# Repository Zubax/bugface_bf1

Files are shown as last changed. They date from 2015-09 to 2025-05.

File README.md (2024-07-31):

# Zubax BugFace BF1

Zubax BugFace BF1 (formerly known as Dronecode Probe) is a generic JTAG/SWD+UART console adapter compatible with most ARM Cortex based designs and in particular with the hardware maintained by the [Dronecode project](http://dronecode.org/).

The design is based on Black Magic Probe and is distributed under open source licenses. The full description of its features and supported targets can be found at the [Black Magic Probe homepage](https://black-magic.org/).

For the manufacturing instructions refer to [MANUFACTURING.md](MANUFACTURING.md).

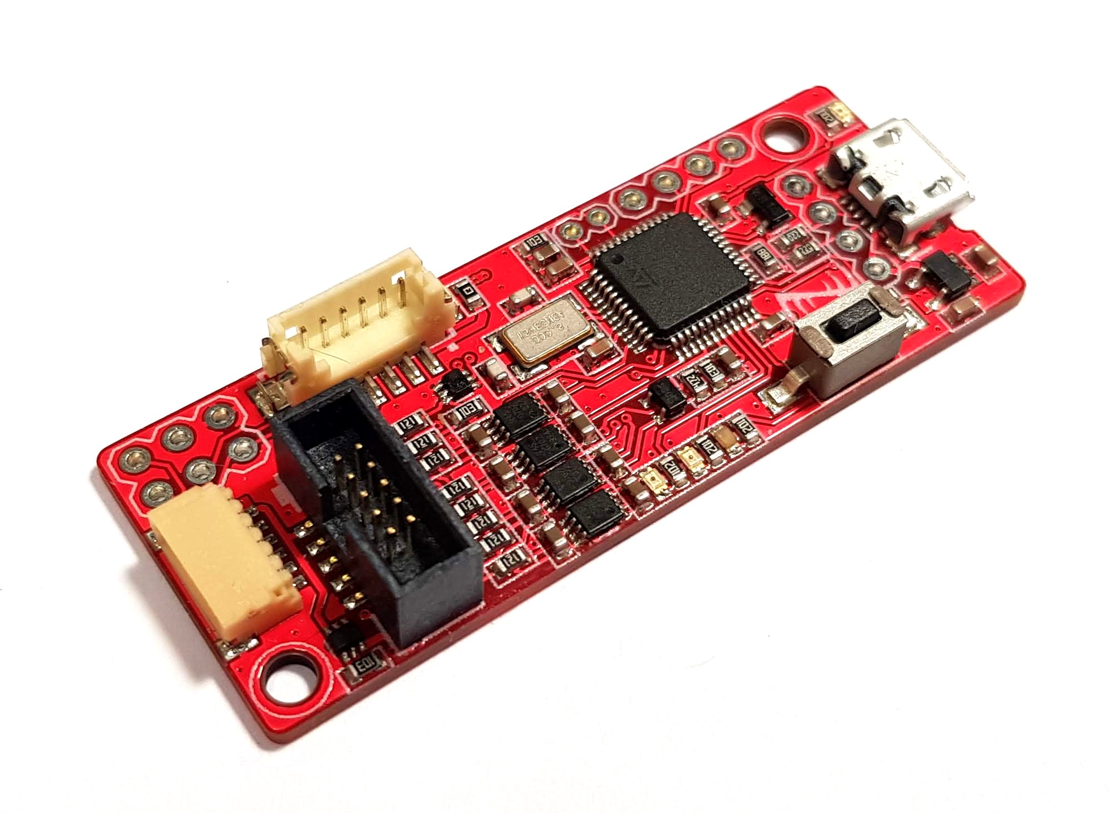
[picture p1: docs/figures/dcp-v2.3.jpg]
dcp-v2-a


## Features

- Some of the supported targets include:
  - STMicroelectronics STM32
  - Microchip/Atmel SAM
  - NXP LPC/Kinetis
  - Texas Instruments LM/TM
  - Silicon Labs EFM32/EZR32
  - Xilinx Zynq-7000
  - Broadcom BCM2836
  - **And many others!** See the [Black Magic Probe homepage](https://black-magic.org/) for the full list of supported targets.

- Embedded GDB server on the device. No host-side driver needed (this is unlike, for example, OpenOCD).
  - Loading the application into flash or RAM.
  - Real-time execution and single-stepping.
  - Hardware assisted breakpoints and read/write/access watchpoints.
  - Software breakpoints when executing from RAM.

- Simple integration with development tools and IDE.
- Connectors are compatible with the Dronecode Autopilot Connector Standard.
- Optional power supply delivery to the target (the power is sourced from USB).

## USB interface

BF1 is a composite USB device that incorporates two virtual serial port interfaces:

1. The first virtual serial port interface is connected to the debugger's embedded GDB server; this interface is used by the host-side debugger to interact with the target. The baud rate and other parameters of a typical serial port are irrelevant for this interface, because it has no physical representation.

2. The second virtual serial port interface is connected to the physical UART interface that can be used to communicate directly with the target's application (for example, this can be used to access the [Serial command line interface (Serial CLI)](https://wiki.zubax.com/public/serial-cli) on the target).

For example, the host may represent the debugger as follows:

- `COM3` (on Windows), or `/dev/serial/by-id/usb-Black_Magic_Debug_Black_Magic_Probe_v1.10.0-836-g254bc265-dirty_C0E079F1-if00` (on GNU/Linux) - this is the GDB interface.
- `COM4` (on Windows), or `/dev/serial/by-id/usb-Black_Magic_Debug_Black_Magic_Probe_v1.10.0-836-g254bc265-dirty_C0E079F1-if02` (on GNU/Linux) - this is the physical UART interface that can be used to interact with the target's application (e.g. a serial CLI).

The device does not require drivers since it uses the standard USB CDC ACM profile. If you're using the device with GNU/Linux, be sure [configure the access permissions correctly](https://wiki.zubax.com/en/public/USB/Using-USB-devices-with-GNULinux).

The USB Vendor ID (VID) is **0x1D50**, and the Product ID (PID) is **0x6018**.

## Connectors

This section documents the available debug interfaces and their connectors, except for the micro-USB since its purpose is evident.

### DCD-M

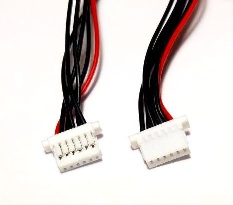
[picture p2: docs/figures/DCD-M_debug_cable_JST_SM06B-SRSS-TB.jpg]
DCD-M debug cable (JST SM06B-SRSS-TB)


The DCD-M connector pinout is documented in the table below. It exposes both SWD and UART interfaces to the target, where UART is typically used to access the debug serial console of the target.

| Pin | Type | Name | Comment |
| --- | --- | --- | --- |
| 1 | IN | `TPWR` | Target power sense; also can be used to power the target. |
| 2 | IN | `UART_RX`| Serial input. |
| 3 | OUT | `UART_TX`| Serial output. |
| 4 | IN/OUT | `SWDIO`  | SWD data line. |
| 5 | OUT | `SWDCLK` | SWD clock line. |
| 6 | GND | `GND` | |

The connector part numbers are as follows:

| Name | Manufacturer  | Part number | Pitch | Datasheet |
| --- | --- | --- | ---| --- |
| DCD-M | JST | **BM06B-SRSS-TB** *(top entry)*, or **SM06B-SRSS-TB** *(side entry)*  | 1 mm  | [http://www.jst-mfg.com/product/pdf/eng/eSH.pdf](http://www.jst-mfg.com/product/pdf/eng/eSH.pdf) |

### ARM Cortex M debug connector

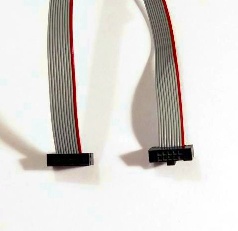
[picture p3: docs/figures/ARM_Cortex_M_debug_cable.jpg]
ARM Cortex M debug cable - 2x5 pins, pitch 1.27 mm

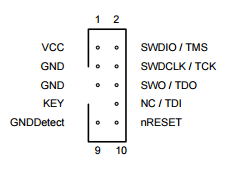
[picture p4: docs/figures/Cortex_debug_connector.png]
ARM Cortex M debug connector - 2x5 pins, pitch 1.27 mm


This is the standard ARM Cortex M debug connector that can be seen on many other ARM debuggers.

| Pin | Name |
| --- | --- |
| 1 | `TPWR` |
| 2 | `SWDIO/TMS` |
| 3 | `GND` |
| 4 | `SWDCLK/TCK` |
| 5 | `GND` |
| 6 | `SWO/TDO` |
| 7 | |
| 8 | `NC/TDI` |
| 9 | `GND` |
| 10  | `nRESET` |

### Pixhawk v1 serial

This connector exposes only the UART interface. It can be used as a general UART port, and its pinout is compatible with the debug serial port on the Pixhawk v1 autopilot.

| Pin | Type | Name | Comment |
| --- | --- | --- | --- |
| 1 | Power OUT | `5V` | Optional 5 V supply output to the target directly from USB.<br><br>Disabled by default; refer to the schematic to see what hardware modifications are required to enable it. |
| 2 | | | Not used |
| 3 | | | Not used |
| 4 | IN | `UART_RX` | Serial input |
| 5 | OUT | `UART_TX` | Serial output |
| 6 | GND | GND | |

## Updating the device's own firmware

Please refer to the following sources:

- <https://black-magic.org/upgrade.html>
- [MANUFACTURING.md](MANUFACTURING.md)

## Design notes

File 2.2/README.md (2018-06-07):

# DroneCode Probe

The DroneCode Probe is a generic JTAG / SWD + UART console adapter compatible with most ARM Cortex based
designs and in particular with hardware maintained by the DroneCode project.
It is a low-cost design with a BOM value around $10.00 and supported on all operating systems (Windows, Linux, Mac OS).

**Documentation: <https://kb.zubax.com/x/iIAh>**

## Key Features / Added Value

- Firmware compatible to the Black Magic probe.
- Does not require OpenOCD or other software to run GDB on Windows, Linux or Mac OS.
- Better setup / usage experience compared to other JTAG probes
- Integrated 3.3V serial adapter for console access
- Solder-free support for common DroneCode cabling options:
  - ARM Mini 10pos standard header
  - DCD-S: DroneCode Debug connector small
  - DCD-M: DroneCode Debug connector medium
  - 6-pos DF13 console cable (Pixhawk 1.x)

## Suggested Packaging Content

JST SUR and JST SH are required as minimum.

- JST SUR 6 pos cable (available from [JST](http://www.jst.com/home9.html) or at lower quantities from 3D Robotics)
- JST SH 6 pos cable ([SparkFun](https://www.sparkfun.com/products/9123))
- ARM Mini cable ([Digi-Key](http://www.digikey.com/product-search/en?x=0&y=0&lang=en&site=us&KeyWords=FFSD-05-D-06.00-01-N))
- Hirose DF13 6-pos cable ([3DR Store](https://store.3drobotics.com/products/df13-6-position-connector-15-cm), or [wires](http://www.digikey.com/product-detail/en/H4BBT-10104-W8/H4BBT-10104-W8-ND/425449)+[headers](http://www.digikey.com/product-search/en?KeyWords=DF13-6S-1.25C&WT.z_header=search_go) from DigiKey)

## License

This project is licensed under the terms of [CC-BY-SA](https://creativecommons.org/licenses/by-sa/3.0/).

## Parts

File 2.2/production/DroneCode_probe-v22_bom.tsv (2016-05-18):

Qty | Value | Device | Package | Parts | DIGIKEY# | PARTNO | Description
1 | 0.01uF | CAP-0402 | 0402-CAP | C2 | 587-2708-1-ND | EMK105B7103KV-F
6 | 0.1uF | CAPACITOR-0402 | 0402-CAP | C4, C5, C6, C7, C8, C9 | 445-7348-1-ND | C1005X7R1E104K050BB
1 | 000 | RESISTOR-0402 | 0402-RES | R22 | P0.0JCT-ND | ERJ-2GE0R00X
1 | 1.5k | RESISTOR-0402 | 0402-RES | R3 | 311-1.50KLRCT-ND | RC0402FR-071K5L
7 | 100R | RESISTOR-0402 | 0402-RES | R1, R2, R6, R7, R11, R12, R13 | 311-100LRCT-ND | RC0402FR-07100RL
3 | 10k | RESISTOR-0402 | 0402-RES | R9, R10, R18 | 311-10.0KLRCT-ND | RC0402FR-0710KL
2 | 18p | C0402 | 402 | C10, C11 | CL05C180JB5NNNC | CL05C180JB5NNNC
2 | 1uF | CAPACITOR-0603 | 0603-CAP | C1, C3 | 311-1372-1-ND | CC0603ZRY5V7BB105
5 | 390R | RESISTOR-0402 | 0402-RES | R5, R16, R17, R19, R20 | 541-390JCT-ND | CRCW0402390RJNED
1 | 4.7k | RESISTOR-0402 | 0402-RES | R8 | P4.70KLCT-ND | ERJ-2RKF4701X
1 | 8MHz | CRYSTAL-NX3225GD | NX3225GD | Z1 | 644-1178-1-ND | NX3225GD-8MHZ-STD-CRA-3 | SMD CRYSTAL
1 | ARM_MINI_JTAGSMT-S | ARM_MINI_JTAGSMT-S | 200215-00010T1LF | J1 | 609-4054-ND | 20021521-00010T1LF | CONNECTOR
1 | DF13-6P-1.25V | DF13-6P-1.25V | DF13C-6P-1.25V | U$1 | H3423-ND | DF13C-6P-1.25V(20) | DF13-6P
1 | GREEN | LED-0603 | 0603-LED | LED1 | 754-1121-1-ND | APT1608SGC
1 | MIC5255-3.3YM5 | V_REG_LDOSMD | SOT23-5 | IC2 | 576-1290-1-ND | MIC5255-3.3YM5 TR | Voltage Regulator LDO
1 | MOLEX-47346-0001 | MOLEX-47346-0001 | MOLEX-47346-0001 | USB1 | WM17141CT-ND | 47346-0001 | MICRO USB B, BOTTOM MOUNT
1 | NDS332P | NDS332P | SOT23B-3 | Q1 | NDS332PCT-ND | NDS332P | MOSFET P-CH 20V 1A SSOT3
1 | NUF2042XV6 | NUF2042XV6 | SOT563-6 | U20 | NUF2042XV6T1GOSCT-ND | NUF2042XV6T1G
1 | RED | LED-0603 | 0603-LED | LED2 | 754-1122-1-ND | APT1608SRCPRV | red smd led
1 | SH06 | SH06 | SH06B | J3 | 455-1806-1-ND | SM06B-SRSS-TB
1 | SM06B-SURS-TF | SM06B-SURS-TF | SM02B-SURS-TF | J2 | SM06B-SURS-TF(LF)(SN)-ND | SM06B-SURS-TF(LF)(SN)
1 | STM32F103CBT6 | STM32F103CBT6 | LQFP48 | IC1 | 497-6288-ND | STM32F103CBT6 | STM32F103 Medium Density 48pins
1 | SWITCH-MOMENTARY-2-FSMSM | SWITCH-MOMENTARY-2-FSMSM | FSMSM | S2 | 450-1140-ND | FSMSM | SWITCH TACTILE SPST-NO 0.05A 24V
2 | YELLOW | LED-0603 | 0603-LED | LED3, LED4 | 754-1125-1-ND | APT1608YC | yellow smd led

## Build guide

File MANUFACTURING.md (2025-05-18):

# BF1 manufacturing

Please open a ticket or reach <info@zubax.com> if questions arise.

## Prerequisites

The instructions below assume that the host computer is running a Linux-based OS.

### Installing dependencies

#### Debian-based systems

The following APT packages must be installed:

* `python-yaml`
* `python-usb`

Also, the ARM GCC toolchain must be installed in order to build the firmware and test the board with GDB.
The toolchain is available from <https://launchpad.net/gcc-arm-embedded>,
or from an APT package `gcc-arm-none-eabi`.
Recommended GCC version is 7.2.

## Assembling

See the assembly drawing in PDF available in this repo.
All components are reflow-solderable.

Keep in mind that certain components are explicitly marked as not to be installed.

## Getting the firmware

Get the sources from <https://github.com/blacksphere/blackmagic> and build them.
The output will contain the following two files (among others):

* `blackmagic_dfu.bin` - the USB DFU bootloader.
* `blackmagic_latest.bin` - the main firmware.

Prebuilt binaries can be found here: <https://files.zubax.com/products/com.zubax.bugface>.

The following comands can be used to create a loadable ELF from a flat binary:

    arm-none-eabi-objcopy -I binary -O elf32-little --change-section-address .data=0x08000000 blackmagic_dfu.bin blackmagic_dfu.elf

## Flashing the firmware for the first time

To upload the firmware for the first time, simply use [`flash_bugface_bf1.sh`](flash_bugface_bf1.sh);
read the usage instructions in the comments.

## Updating the firmware via DFU

If you want to replace an already uploaded firmware, you can also do it as described in this section.

Connect the board to USB while holding the button `BOOT`.
All LEDs on the board should start blinking alernately.
The system will report the device as follows:

```
$ sudo dmesg
usb 3-1.4.1: new full-speed USB device number 16 using xhci_hcd
usb 3-1.4.1: New USB device found, idVendor=1d50, idProduct=6017
usb 3-1.4.1: New USB device strings: Mfr=1, Product=2, SerialNumber=3
usb 3-1.4.1: Product: Black Magic Probe (Upgrade)
usb 3-1.4.1: Manufacturer: Black Sphere Technologies
usb 3-1.4.1: SerialNumber: 7ECB8AC5
```

Then go to the directory with firmware sources and execute the following script:

```bash
sudo dfu-util -d 1d50:6017 -s 0x08002000:leave -R -D src/blackmagic.bin
```
The following information will be reported in the console:

```
Opening DFU capable USB device...
ID 1d50:6017
Run-time device DFU version 011a
Claiming USB DFU Interface...
Setting Alternate Setting #0 ...
Determining device status: state = dfuIDLE, status = 0
dfuIDLE, continuing
DFU mode device DFU version 011a
Device returned transfer size 1024
DfuSe interface name: "Internal Flash   "
Downloading to address = 0x08002000, size = 120004
Download	[=========================] 100%       120004 bytes
Download done.
```

Disconnect the board afterwards.

Alternative instructions for this step are available from
<https://github.com/blacksphere/blackmagic/wiki/Upgrading-Firmware>.

## Testing

Disconnect the newly flashed board from USB, then connect again.
The system will detect a new CDC-ACM device:

```
$ dmesg
usb 3-1.4.1: new full-speed USB device number 19 using xhci_hcd
usb 3-1.4.1: New USB device found, idVendor=1d50, idProduct=6018
usb 3-1.4.1: New USB device strings: Mfr=1, Product=2, SerialNumber=3
usb 3-1.4.1: Product: Black Magic Probe
usb 3-1.4.1: Manufacturer: Black Sphere Technologies
usb 3-1.4.1: SerialNumber: 7ECB8AC5
cdc_acm 3-1.4.1:1.0: ttyACM0: USB ACM device
cdc_acm 3-1.4.1:1.2: ttyACM1: USB ACM device
```

Connect the board to a target (e.g. another unflashed BF1, as described in one of the steps above)
and try to load its firmware using GDB.
For example, start `arm-none-eabi-gdb` providing path to the ELF,
and execute the following commands in the internal command prompt:

```
tar ext /dev/ttyACM0    # Or another port
mon swdp_scan
attach 1
load
kill
```

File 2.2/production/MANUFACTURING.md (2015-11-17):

# DroneCode Probe manufacturing

Please open a ticket or reach <info@zubax.com> if questions arise.

## Prerequisites

The instructions below assume that the host computer is running a Linux-based OS.

### Installing dependencies

#### Debian-based systems

The following APT packages must be installed:

* `python-yaml`
* `python-usb`

Also, the ARM GCC toolchain must be installed in order to build the firmware and test the board with GDB.
The toolchain is available from <https://launchpad.net/gcc-arm-embedded>,
or from an APT package `gcc-arm-none-eabi`.
Recommended GCC version is 4.9.

## Assembling

See the assembly drawing in PDF available in this repo.
All components are reflow-solderable.

Keep in mind that certain components are explicitly marked as not to be installed.

## Getting the firmware

Get the sources from <https://github.com/blacksphere/blackmagic> and build them.
The output will contain the following two files (among others):

* `blackmagic_dfu.bin` - DFU bootloader.
* `blackmagic.bin` - main firmware.

Prebuilt binaries can be found here: <https://files.zubax.com/products/dronecode_probe>.

## Flashing the DFU bootloader

Flash the DFU bootloader image using one of the methods below.

### Using STM32 serial bootloader

1. Using tweezers, close the jumper `BOOT0` and connect the board to USB
(note that the jumper itself is marked as not to be installed).
The microcontroller will start the embedded bootloader, accessible via the serial port.
Once the board is powered, the tweezers can be removed.
2. Using any available STM32 serial bootloader tool, load the DFU bootloader image onto the board at zero offset
(i.e. 0x08000000, which is the address of flash).
3. Disconnect the board from USB.

It is adviced to use the following tool for flashing: <https://github.com/Zubax/zubax_serial_updater>.

### Using JTAG/SWD

This option will require an adapter cable, with ARM Cortex debug connector (1.27mm 2x5) on one end
and any of DroneCode debug connectors on the other end. The pinout of the cable must be as follows:

ARM Cortex debug connector      | DroneCode debug connector (any type)
--------------------------------|-------------------------------------
`GND` (pin 3 or 5)              | `GND` (pin 6)
`SWDIO/TMS` (pin 2)             | `UART_RX` (pin 2)
`SWDCLK/TDO` (pin 4)            | `UART_TX` (pin 3)

Steps:

1. Install resistors (or short with solder blobs) between the microcontroller's own SWD interface and UART signals.
Currently their designators are R14 and R15.
2. Connect one end of the adapter cable to a JTAG/SWD adapter (e.g. to an another DroneCode Probe that is already
flashed), and the other end to the corresponding DroneCode debug connector of the target device.
3. Using any of the available tools, flash the DFU bootloader image to the target board with
zero offset from the start of the flash memory.
4. Disconnect the target board.

The following script can be used to create a loadable ELF from a flat binary: <https://gist.github.com/tangrs/4030336>.
Usage example:

    ./bin2elf.sh blackmagic_dfu.bin blackmagic_dfu.elf 0x08000000

## Flashing the main firmware

Connect the board to USB while holding the button `BOOT`.
The red LED on the board should start blinking.
The system will report the device as follows:

```
$ dmesg
usb 2-6.2.3: new full-speed USB device number 12 using ehci-pci
usb 2-6.2.3: New USB device found, idVendor=1d50, idProduct=6017
usb 2-6.2.3: New USB device strings: Mfr=1, Product=2, SerialNumber=3
usb 2-6.2.3: Product: Black Magic Probe (Upgrade)
usb 2-6.2.3: Manufacturer: Black Sphere Technologies
usb 2-6.2.3: SerialNumber: B5DCABF5
```

Then go to the directory with firmware sources and execute the following script:

```bash
sudo scripts/stm32_mem.py src/blackmagic.bin
```

Disconnect the board afterwards.

Alternative instructions for this step are available from
<http://px4.io/dev/jtag/black_magic_probe#instructions_for_linux>.

## Testing

Disconnect the newly flashed board from USB, then connect again.
The system will detect a new CDC-ACM device:

```
$ dmesg
usb 2-6.2.3: new full-speed USB device number 9 using ehci-pci
usb 2-6.2.3: New USB device found, idVendor=1d50, idProduct=6018
usb 2-6.2.3: New USB device strings: Mfr=1, Product=2, SerialNumber=3
usb 2-6.2.3: Product: Black Magic Probe
usb 2-6.2.3: Manufacturer: Black Sphere Technologies
usb 2-6.2.3: SerialNumber: B5DCABF5
cdc_acm 2-6.2.3:1.0: This device cannot do calls on its own. It is not a modem.
cdc_acm 2-6.2.3:1.0: ttyACM0: USB ACM device
cdc_acm 2-6.2.3:1.2: This device cannot do calls on its own. It is not a modem.
cdc_acm 2-6.2.3:1.2: ttyACM1: USB ACM device
usbcore: registered new interface driver cdc_acm
cdc_acm: USB Abstract Control Model driver for USB modems and ISDN adapters
```

Connect the board to a target (e.g. another unflashed DroneCode Probe, as described in one of the steps above)
and try to load a firmware using GDB.
For example, start `arm-none-eabi-gdb` providing path to the ELF,
and execute the following commands in the internal command prompt:

```
tar ext /dev/ttyACM0    # Or another port
mon swdp_scan
attach 1
load
```

The steps can be automated with a script, e.g.
<https://github.com/Zubax/zubax_rtems/blob/master/flashers/flash_via_blackmagic.sh>.

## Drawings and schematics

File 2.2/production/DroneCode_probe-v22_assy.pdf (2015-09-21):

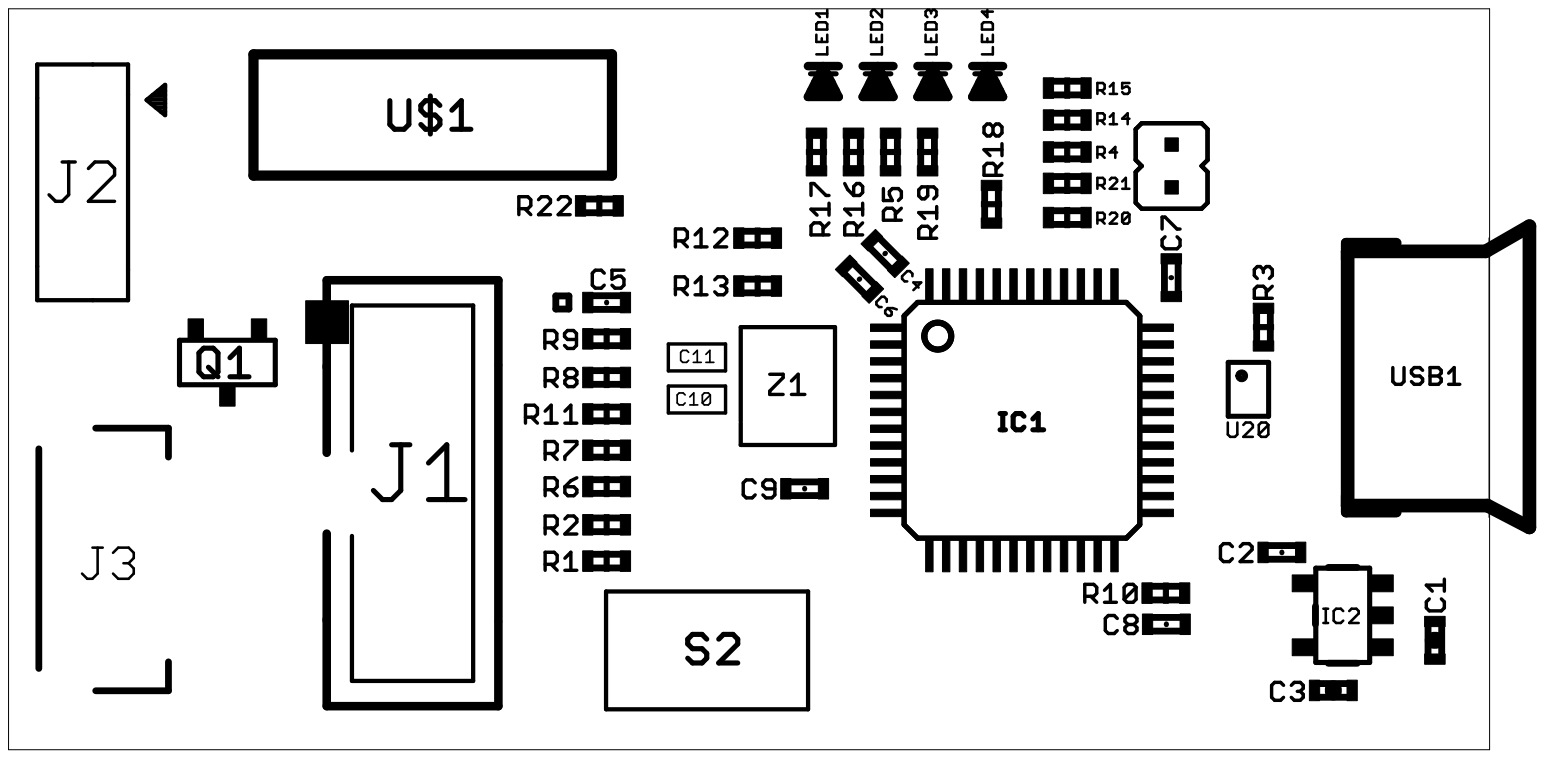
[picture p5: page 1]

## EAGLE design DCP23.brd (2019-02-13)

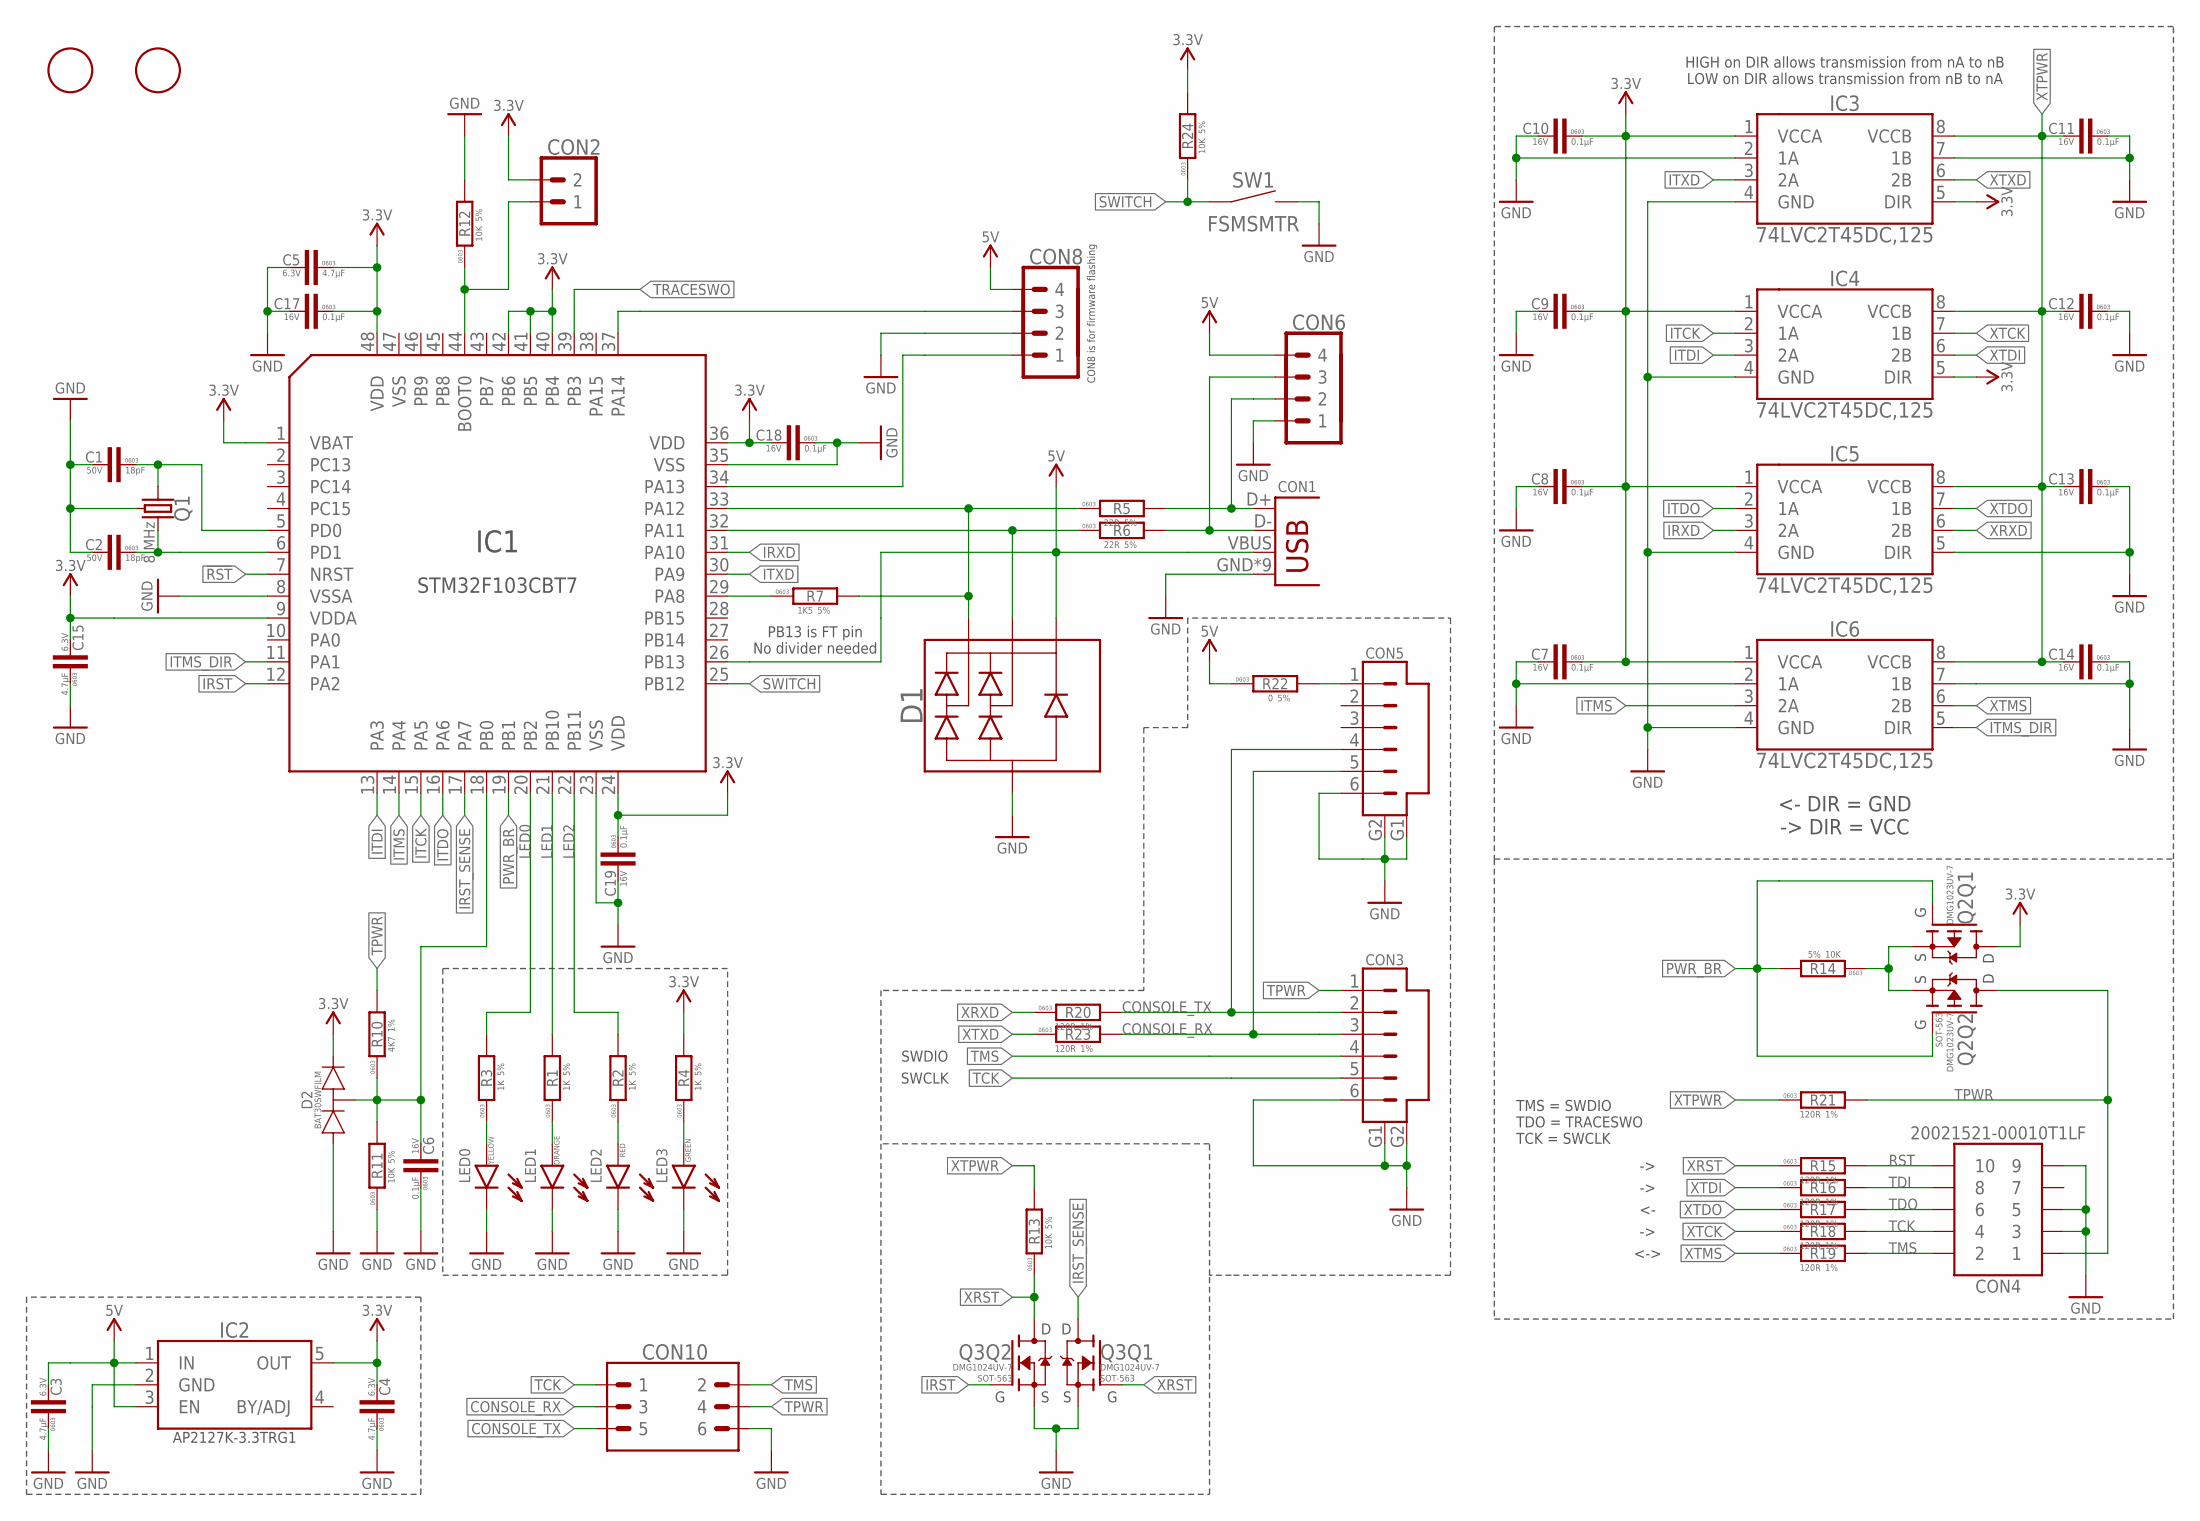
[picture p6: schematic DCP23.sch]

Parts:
C1, C2: 18pF; C0603
C3, C4, C5, C15: 4.7µF; C0603
C6, C7, C8, C9, C10, C11, C12, C13, C14, C17, C18, C19: 0.1µF; C0603
CON1: USB-1; MICRO_USB_WITH_PEGS
CON2: PINHEAD_1X02-2; 1X02-PTH-2
CON3: CON-6P-SM06B; SM06B
CON4: CON-2X5P; 200215-00010T1LF
CON5: CON-6P-DF13; DF13C-6P-1.25V
CON6, CON8: PINHEAD_1X04-2.54; 1X04-PTH-2.54
CON10: PINHEAD_2X03-PTH-2.54; 2X03-PTH-2.54
D1: PRTR5V0U2X; SOT143B
D2: BAT30SWFILM; SC70
IC1: STM32F103CBT7; LQFP48
IC2: AP2127-3.3; SOT23-5
IC3, IC4, IC5, IC6: 74LVC2T45; VSSOP8
LED0: LED-0603; LED0603; DIGIKEY# 160-1448-1-ND
LED1: LED-0603; LED0603; DIGIKEY# 160-1445-1-ND
LED2: LED-0603; LED0603; DIGIKEY# SML-D12U1WT86CT-ND
LED3: LED-0603; LED0603; DIGIKEY# 160-1446-1-ND
Q1: 8 MHz; OSCILLATOR-5.0X3.2-4P
Q2: DMG1023UV-7; SOT-563
Q3: DMG1024UV-7; SOT-563
R1, R2, R3, R4: 1K; R0603
R5, R6: 22R; R0603; DIGIKEY# 311-22NCT-ND
R7: 1K5; R0603; DIGIKEY# 311-1.50KHRCT-ND
R10: 4K7; R0603
R11, R12, R13, R14, R24: 10K; R0603
R15, R16, R17, R18, R19, R20, R21, R23: 120R; R0603
R22: 0; R0603
SW1: TACT_SWITCH-FSMSM; FSMSM
U$9, U$10: FIDUCIALMOUNT; FIDUCIA-MOUNT

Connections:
!RST: IC1.7 (NRST)
CONSOLE_RX: CON3.3, CON5.5, CON10.3, R23.P$2 (2)
CONSOLE_TX: CON3.2, CON5.4, CON10.5, R20.P$2 (2)
GND: C1.P$2 (2), C2.P$2 (2), C3.P$1 (1), C4.P$1 (1), C5.P$2 (2), C6.P$1 (1), C7.P$2 (2), C8.P$2 (2), C9.P$2 (2), C10.P$2 (2), C11.P$1 (1), C12.P$1 (1), C13.P$1 (1), C14.P$1 (1), C15.P$1 (1), C17.P$2 (2), C18.P$1 (1), C19.P$2 (2), CON1.GND, CON1.GND1 (GND), CON1.GND2 (GND), CON1.GND3 (GND), CON1.GND4 (GND), CON1.P$1 (GND), CON1.P$2 (GND), CON1.P$3 (GND), CON1.P$4 (GND), CON3.6, CON3.G1, CON3.G2, CON4.3, CON4.5, CON4.9, CON5.6, CON5.G1 (G2), CON5.G2 (G1), CON6.1, CON8.2, CON10.6, D1.1 (C), D2.1 (A), IC1.8 (VSSA), IC1.23 (VSS), IC1.35 (VSS), IC2.2 (GND), IC3.2 (1A), IC3.4 (GND), IC3.7 (1B), IC4.4 (GND), IC5.4 (GND), IC5.5 (DIR), IC6.2 (1A), IC6.4 (GND), IC6.7 (1B), LED0.C, LED1.C, LED2.C, LED3.C, Q1.2 (GND), Q1.4 (GND), Q3.1 (S), Q3.4 (S), R11.P$1 (1), R12.P$2 (2), SW1.P$2 (2)
IRST: IC1.12 (PA2), Q3.5 (G)
IRST_SENSE: IC1.17 (PA7), Q3.6 (D)
IRXD: IC1.31 (PA10), IC5.3 (2A)
ITCK: IC1.15 (PA5), IC4.2 (1A)
ITDI: IC1.13 (PA3), IC4.3 (2A)
ITDO: IC1.16 (PA6), IC5.2 (1A)
ITMS: IC1.14 (PA4), IC6.3 (2A)
ITMS_DIR: IC1.11 (PA1), IC6.5 (DIR)
ITXD: IC1.30 (PA9), IC3.3 (2A)
LED0: IC1.20 (PB2), R3.P$2 (2)
LED1: IC1.21 (PB10), R1.P$2 (2)
LED2: IC1.22 (PB11), R2.P$2 (2)
unnamed: C1.P$1 (1), IC1.5 (PD0), Q1.1
unnamed: LED0.A, R3.P$1 (1)
unnamed: C2.P$1 (1), IC1.6 (PD1), Q1.3 (2)
unnamed: LED2.A, R2.P$1 (1)
unnamed: LED1.A, R1.P$1 (1)
unnamed: LED3.A, R4.P$1 (1)
unnamed: IC1.29 (PA8), R7.1
unnamed: D1.3 (D2), IC1.32 (PA11), R6.1
unnamed: D1.2 (D1), IC1.33 (PA12), R5.1, R7.2
unnamed: Q2.1 (S), Q2.4 (S), R14.P$1 (1)
unnamed: CON5.1, R22.P$2 (2)
unnamed: CON2.1, IC1.44 (BOOT0), R12.P$1 (1)
PWR_BR: IC1.19 (PB1), Q2.2 (G), Q2.5 (G), R14.P$2 (2)
RST: CON4.10, R15.P$2 (2)
SWCLK: CON8.3, IC1.37 (PA14)
SWDIO: CON8.1, IC1.34 (PA13)
SWITCH: IC1.25 (PB12), R24.P$1 (1), SW1.P$1 (1)
TCK: CON3.5, CON4.4, CON10.1, R18.P$2 (2)
TDI: CON4.8, R16.P$2 (2)
TDO: CON4.6, R17.P$2 (2)
TMS: CON3.4, CON4.2, CON10.2, R19.P$2 (2)
TPWR: CON3.1, CON4.1, CON10.4, Q2.6 (D), R10.P$2 (2), R21.P$2 (2)
TRACESWO: IC1.39 (PB3)
USB_DM: CON1.D-, CON6.3, R6.2
USB_DP: CON1.D+, CON6.2, R5.2
VBUS1: C6.P$2 (2), D2.3 (COMMON), IC1.18 (PB0), R10.P$1 (1), R11.P$2 (2)
VDD_3V3: C4.P$2 (2), C5.P$1 (1), C7.P$1 (1), C8.P$1 (1), C9.P$1 (1), C10.P$1 (1), C15.P$2 (2), C17.P$1 (1), C18.P$2 (2), C19.P$1 (1), CON2.2, D2.2 (C), IC1.1 (VBAT), IC1.9 (VDDA), IC1.24 (VDD), IC1.36 (VDD), IC1.40 (PB4), IC1.41 (PB5), IC1.42 (PB6), IC1.48 (VDD), IC2.5 (OUT), IC3.1 (VCCA), IC3.5 (DIR), IC4.1 (VCCA), IC4.5 (DIR), IC5.1 (VCCA), IC6.1 (VCCA), Q2.3 (D), R4.P$2 (2), R24.P$2 (2)
VDD_5V: C3.P$2 (2), CON1.VBUS, CON6.4, CON8.4, D1.4 (A), IC1.26 (PB13), IC2.1 (IN), IC2.3 (EN), R22.P$1 (1)
XRST: Q3.2 (G), Q3.3 (D), R13.P$1 (1), R15.P$1 (1)
XRXD: IC5.6 (2B), R20.P$1 (1)
XTCK: IC4.7 (1B), R18.P$1 (1)
XTDI: IC4.6 (2B), R16.P$1 (1)
XTDO: IC5.7 (1B), R17.P$1 (1)
XTMS: IC6.6 (2B), R19.P$1 (1)
XTPWR: C11.P$2 (2), C12.P$2 (2), C13.P$2 (2), C14.P$2 (2), IC3.8 (VCCB), IC4.8 (VCCB), IC5.8 (VCCB), IC6.8 (VCCB), R13.P$2 (2), R21.P$1 (1)
XTXD: IC3.6 (2B), R23.P$1 (1)

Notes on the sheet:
<- DIR = GND -> DIR = VCC
TMS = SWDIO TDO = TRACESWO TCK = SWCLK
<->
HIGH on DIR allows transmission from nA to nB LOW on DIR allows transmission from nB to nA
SWDIO
SWCLK
CON8 is for firmware flashing
PB13 is FT pin No divider needed

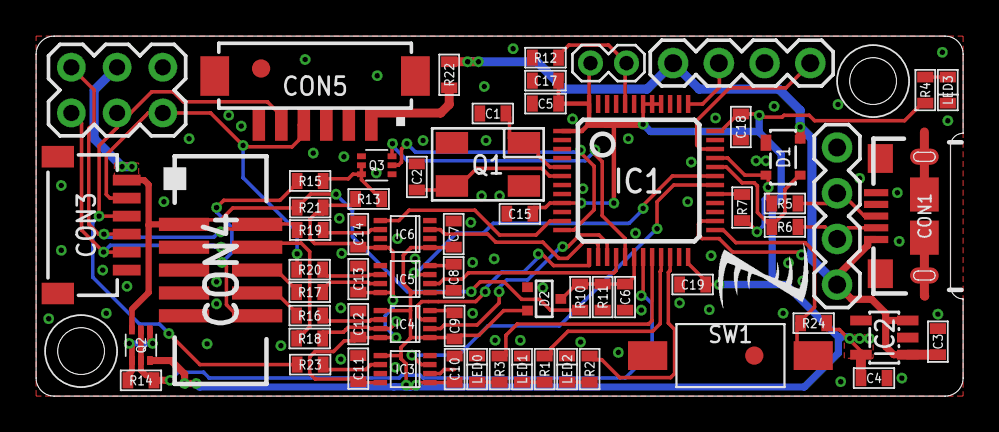
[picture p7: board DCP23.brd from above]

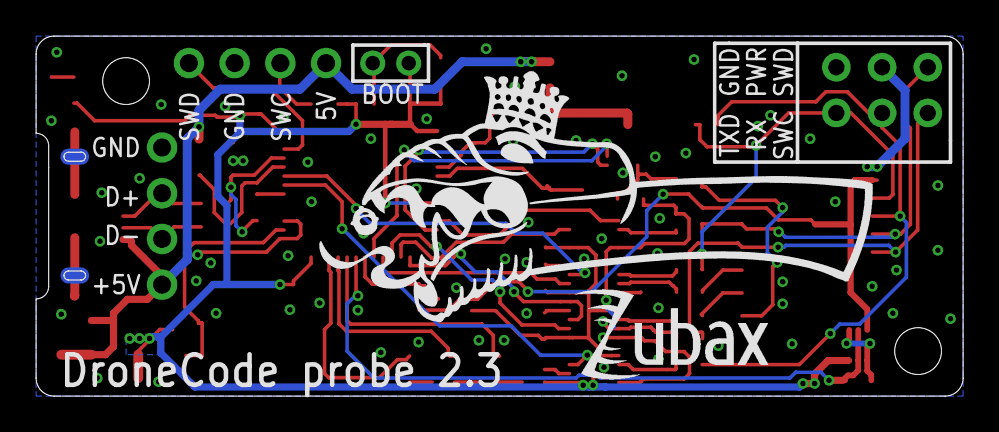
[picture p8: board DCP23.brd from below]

Board: 2 copper layers, 51.5 x 20.0 mm, 69 parts (2 on the bottom side), 50 nets.

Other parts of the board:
U$1: DRAGON-30X13
U$2: Z_LOGO_5
U$3: ZUBAX_LOGO_5X10

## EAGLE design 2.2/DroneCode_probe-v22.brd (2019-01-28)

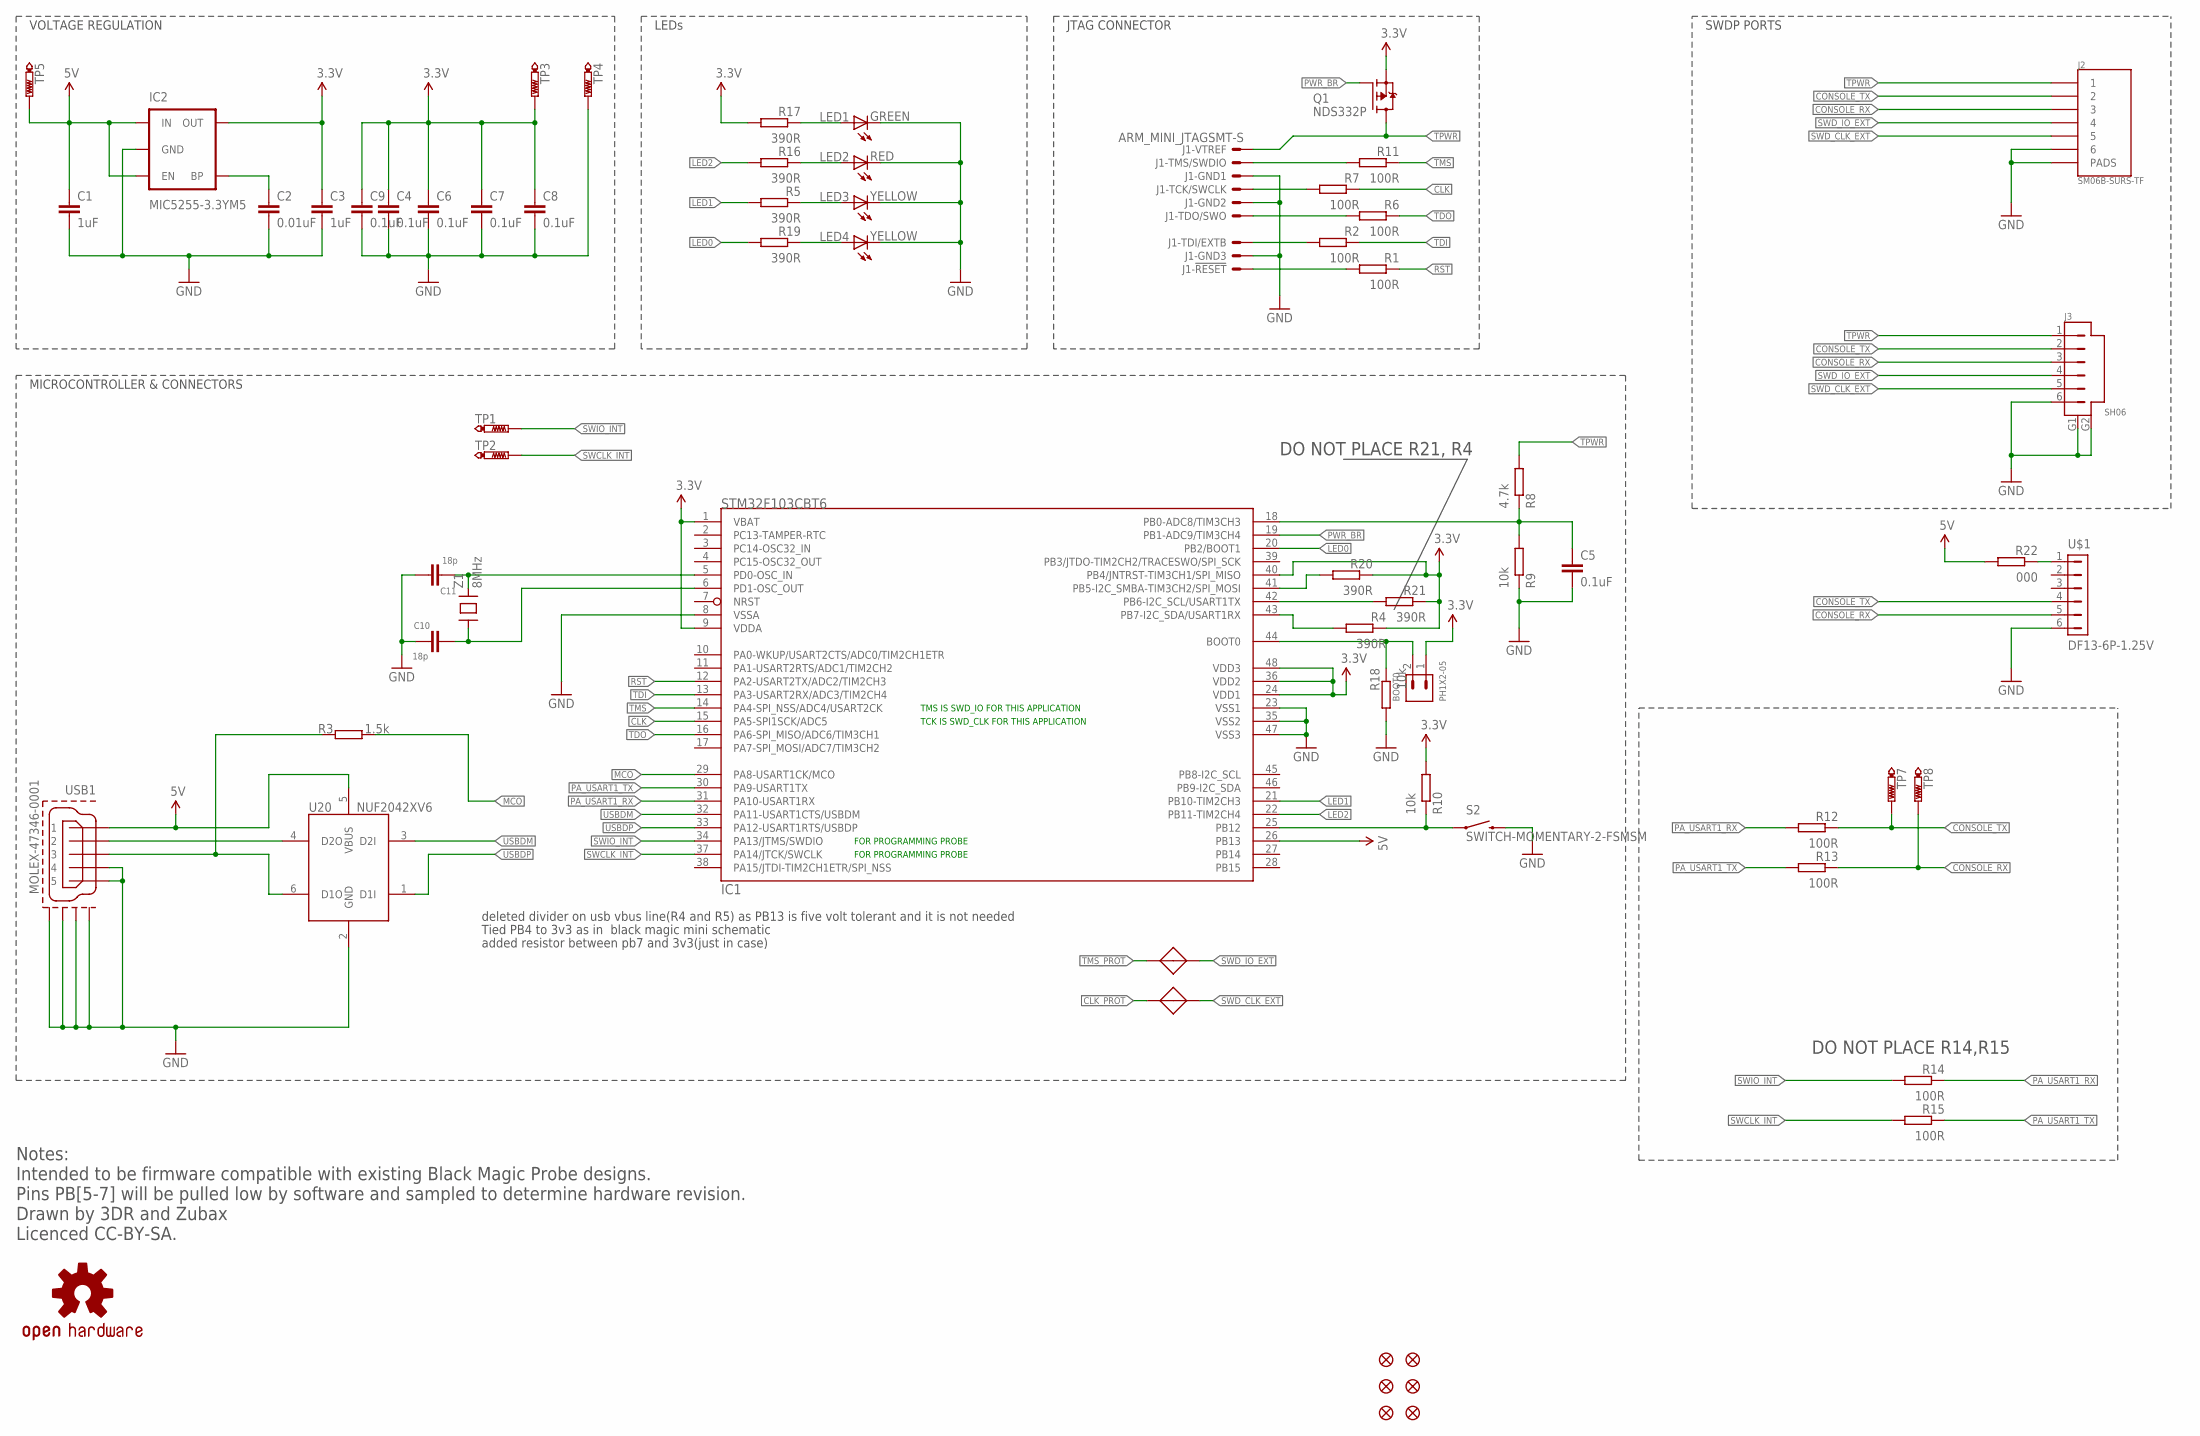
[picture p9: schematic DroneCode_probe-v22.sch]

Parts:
BOOT0: PH1X2-05; PH005-1-2
C1, C3: 1uF; 0603-CAP; PARTNO CC0603ZRY5V7BB105; DIGIKEY# 311-1372-1-ND
C2: 0.01uF; 0402-CAP; PARTNO EMK105B7103KV-F; DIGIKEY# 587-2708-1-ND
C4, C5, C6, C7, C8, C9: 0.1uF; 0402-CAP; PARTNO C1005X7R1E104K050BB; DIGIKEY# 445-7348-1-ND
C10, C11: 18p; 0402; DIGIKEY# CL05C180JB5NNNC
IC1: STM32F103CBT6; LQFP48; PARTNO STM32F103CBT6; DIGIKEY# 497-6288-ND
IC2: MIC5255-3.3YM5; SOT23-5; PARTNO MIC5255-3.3YM5 TR; DIGIKEY# 576-1290-1-ND
J1: ARM_MINI_JTAGSMT-S; 200215-00010T1LF; PARTNO 20021521-00010T1LF; DIGIKEY# 609-4054-ND
J2: SM06B-SURS-TF; SM02B-SURS-TF; PARTNO SM06B-SURS-TF(LF)(SN); DIGIKEY# SM06B-SURS-TF(LF)(SN)-ND
J3: SH06; SH06B; PARTNO SM06B-SRSS-TB; DIGIKEY# 455-1806-1-ND
J4, J5: JUNCTION
JP1, JP2, JP3, JP4, JP5, JP6: FIDUCIAL1X2; FIDUCIAL-1X2
LED1: GREEN; 0603-LED; PARTNO APT1608SGC; DIGIKEY# 754-1121-1-ND
LED2: RED; 0603-LED; PARTNO APT1608SRCPRV; DIGIKEY# 754-1122-1-ND
LED3, LED4: YELLOW; 0603-LED; PARTNO APT1608YC; DIGIKEY# 754-1125-1-ND
Q1: NDS332P; SOT23B-3
R1, R2, R6, R7, R11, R12, R13, R14, R15: 100R; 0402-RES; PARTNO RC0402FR-07100RL; DIGIKEY# 311-100LRCT-ND
R3: 1.5k; 0402-RES; PARTNO RC0402FR-071K5L; DIGIKEY# 311-1.50KLRCT-ND
R4, R5, R16, R17, R19, R20, R21: 390R; 0402-RES; PARTNO CRCW0402390RJNED; DIGIKEY# 541-390JCT-ND
R8: 4.7k; 0402-RES; PARTNO ERJ-2RKF4701X; DIGIKEY# P4.70KLCT-ND
R9, R10, R18: 10k; 0402-RES; PARTNO RC0402FR-0710KL; DIGIKEY# 311-10.0KLRCT-ND
R22: 000; 0402-RES; PARTNO ERJ-2GE0R00X; DIGIKEY# P0.0JCT-ND
S2: SWITCH-MOMENTARY-2-FSMSM; FSMSM
TP1, TP2, TP3, TP4, TP5, TP7, TP8: PTR1B1,27; B1,27
U20: NUF2042XV6; SOT563-6; PARTNO NUF2042XV6T1G; DIGIKEY# NUF2042XV6T1GOSCT-ND
U$1: DF13-6P-1.25V; DF13C-6P-1.25V; PARTNO DF13C-6P-1.25V(20); DIGIKEY# H3423-ND
U$5: OSHW-LOGOL; OSHW-LOGO-L
USB1: MOLEX-47346-0001; PARTNO 47346-0001; DIGIKEY# WM17141CT-ND
Z1: 8MHz; NX3225GD

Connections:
3.3V: BOOT0.1, C3.P$1 (1), C4.P$1 (1), C6.P$1 (1), C7.P$1 (1), C8.P$1 (1), C9.P$1 (1), IC1.1 (VBAT), IC1.9 (VDDA), IC1.24 (VDD1), IC1.36 (VDD2), IC1.40 (PB4/JNTRST-TIM3CH1/SPI_MISO), IC1.48 (VDD3), IC2.5 (OUT), Q1.S, R4.P$1 (1), R10.P$2 (2), R17.P$2 (2), R20.P$1 (1), R21.P$1 (1), TP3.TP
5V: C1.P$1 (1), IC1.26 (PB13), IC2.1 (IN), IC2.3 (EN), R22.P$2 (2), TP5.TP, U20.5 (VBUS), USB1.VBUS (1)
CLK: IC1.15 (PA5-SPI1SCK/ADC5), R7.P$1 (1)
CLK_PROT: J1.4, J5.P$1 (1), R7.P$2 (2)
CONSOLE_RX: J2.3, J3.3, R13.P$1 (1), TP8.TP, U$1.5
CONSOLE_TX: J2.2, J3.2, R12.P$1 (1), TP7.TP, U$1.4
GND: C1.P$2 (2), C2.P$2 (2), C3.P$2 (2), C4.P$2 (2), C5.P$2 (2), C6.P$2 (2), C7.P$2 (2), C8.P$2 (2), C9.P$2 (2), C10.2, C11.1, IC1.8 (VSSA), IC1.23 (VSS1), IC1.35 (VSS2), IC1.47 (VSS3), IC2.2 (GND), J1.3, J1.5, J1.9, J2.6, J2.PAD-L (PADS), J2.PAD-R (PADS), J3.6, J3.G1, J3.G2, LED1.C, LED2.C, LED3.C, LED4.C, R9.P$1 (1), R18.P$2 (2), S2.P$2 (2), TP4.TP, U20.2 (GND), U$1.6, USB1.GND (5), USB1.GND1, USB1.GND2, USB1.GND3, USB1.GND4, USB1.ID (4)
LED0: IC1.20 (PB2/BOOT1), R19.P$2 (2)
LED1: IC1.21 (PB10-TIM2CH3), R5.P$2 (2)
LED2: IC1.22 (PB11-TIM2CH4), R16.P$2 (2)
MCO: IC1.29 (PA8-USART1CK/MCO), R3.P$2 (2)
unnamed: U20.4 (D2O), USB1.D- (2)
unnamed: C2.P$1 (1), IC2.4 (BP)
unnamed: R3.P$1 (1), U20.6 (D1O), USB1.D+ (3)
unnamed: IC1.43 (PB7-I2C_SDA/USART1RX), R4.P$2 (2)
unnamed: BOOT0.2, IC1.44 (BOOT0), R18.P$1 (1)
unnamed: R22.P$1 (1), U$1.1
unnamed: IC1.41 (PB5-I2C_SMBA-TIM3CH2/SPI_MOSI), R20.P$2 (2)
unnamed: IC1.42 (PB6-I2C_SCL/USART1TX), R21.P$2 (2)
unnamed: C5.P$1 (1), IC1.18 (PB0-ADC8/TIM3CH3), R8.P$1 (1), R9.P$2 (2)
unnamed: IC1.25 (PB12), R10.P$1 (1), S2.P$1 (1)
unnamed: LED1.A, R17.P$1 (1)
unnamed: LED2.A, R16.P$1 (1)
unnamed: LED3.A, R5.P$1 (1)
unnamed: LED4.A, R19.P$1 (1)
unnamed: C11.2, IC1.5 (PD0-OSC_IN), Z1.2
unnamed: C10.1, IC1.6 (PD1-OSC_OUT), Z1.1
PA_USART1_RX: IC1.31 (PA10-USART1RX), R12.P$2 (2), R14.P$1 (1)
PA_USART1_TX: IC1.30 (PA9-USART1TX), R13.P$2 (2), R15.P$1 (1)
PWR_BR: IC1.19 (PB1-ADC9/TIM3CH4), Q1.G
RST: IC1.12 (PA2-USART2TX/ADC2/TIM2CH3), R1.P$1 (1)
RST_PROT: J1.10, R1.P$2 (2)
SWCLK_INT: IC1.37 (PA14/JTCK/SWCLK), R15.P$2 (2), TP2.TP
SWD_CLK_EXT: J2.5, J3.5, J5.P$2 (2)
SWD_IO_EXT: J2.4, J3.4, J4.P$2 (2)
SWIO_INT: IC1.34 (PA13/JTMS/SWDIO), R14.P$2 (2), TP1.TP
TDI: IC1.13 (PA3-USART2RX/ADC3/TIM2CH4), R2.P$1 (1)
TDI_PROT: J1.8, R2.P$2 (2)
TDO: IC1.16 (PA6-SPI_MISO/ADC6/TIM3CH1), R6.P$1 (1)
TDO_PROT: J1.6, R6.P$2 (2)
TMS: IC1.14 (PA4-SPI_NSS/ADC4/USART2CK), R11.P$1 (1)
TMS_PROT: J1.2, J4.P$1 (1), R11.P$2 (2)
TPWR: J1.1, J2.1, J3.1, Q1.D, R8.P$2 (2)
USBDM: IC1.32 (PA11-USART1CTS/USBDM), U20.3 (D2I)
USBDP: IC1.33 (PA12-USART1RTS/USBDP), U20.1 (D1I)

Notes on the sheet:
Notes: Intended to be firmware compatible with existing Black Magic Probe designs. Pins PB[5-7] will be pulled low by software and sampled to determine hardware revision. Drawn by 3DR and Zubax Licenced CC-BY-SA.
VOLTAGE REGULATION
LEDs
JTAG CONNECTOR
MICROCONTROLLER & CONNECTORS
FOR PROGRAMMING PROBE
TCK IS SWD_CLK FOR THIS APPLICATION
TMS IS SWD_IO FOR THIS APPLICATION
SWDP PORTS
deleted divider on usb vbus line(R4 and R5) as PB13 is five volt tolerant and it is not needed
Tied PB4 to 3v3 as in black magic mini schematic
added resistor between pb7 and 3v3(just in case)
DO NOT PLACE R14,R15
DO NOT PLACE R21, R4

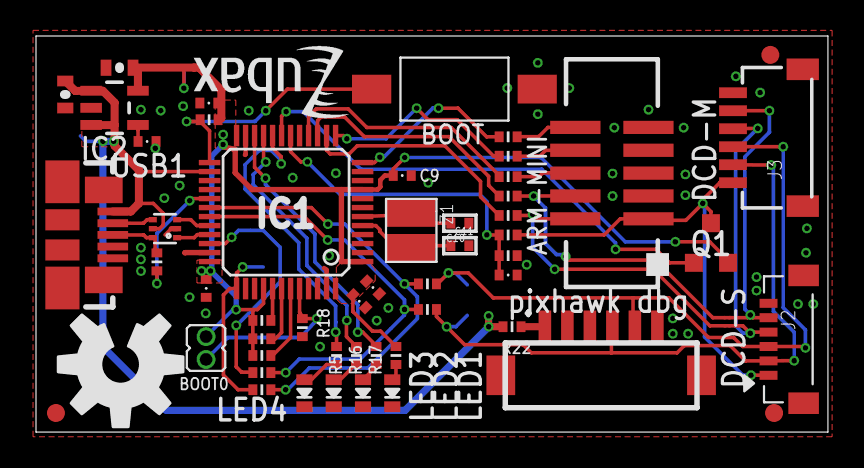
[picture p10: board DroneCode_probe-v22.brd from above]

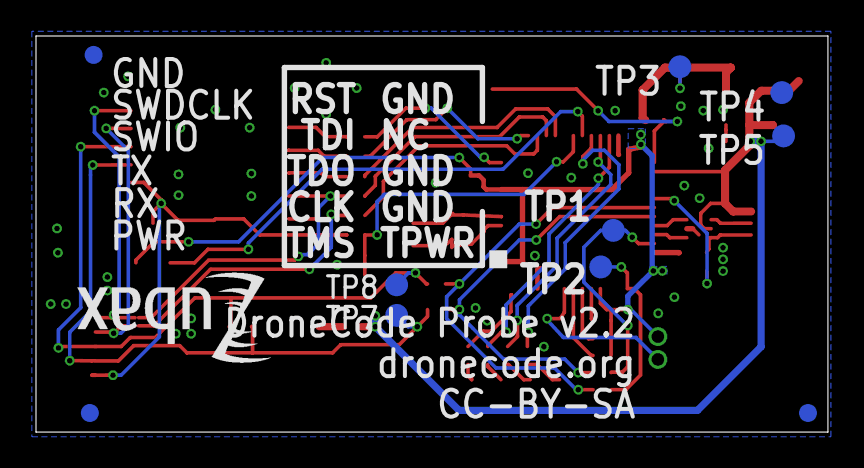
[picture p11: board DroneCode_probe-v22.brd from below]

Board: 2 copper layers, 44.0 x 22.0 mm, 67 parts (11 on the bottom side), 45 nets.

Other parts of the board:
U$7: ZUBAX_LOGO_4X8
U$8: ZUBAX_LOGO_5X10

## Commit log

2015-07-30 BOM converted to CSV
    [DroneCode_probe-v22_bom.csv, DroneCode_probe-v22_bom.xls]
2015-08-04 CSV formatting fix - comments removed
    [DroneCode_probe-v22_bom.csv]
2015-08-06 Cable sources
2015-09-21 -Added assembly file
2016-05-18 Fixed typo in BOM
    Schematic also needs update
    [DroneCode_probe-v22_bom.tsv]
2017-02-15 -added gerber files
2019-02-06 2.3 schematic completed
    [DCP23.brd, DCP23.sch]
2019-02-06 Some routing
    [DCP23.brd, DCP23.sch]
2019-02-07 more routing
    [DCP23.brd, DCP23.sch]
2019-02-07 more routong
    [DCP23.brd, DCP23.sch]
2019-02-13 DroneCode probe V2.3
    [BOM.csv, DCP23.brd, DCP23.sch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]
2024-07-31 update readme (#9)
    move the kb page here from https://kb.zubax.com/display/MAINKB/Dronecode+Probe+documentation
    ---------

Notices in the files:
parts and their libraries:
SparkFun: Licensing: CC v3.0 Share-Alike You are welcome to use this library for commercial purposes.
